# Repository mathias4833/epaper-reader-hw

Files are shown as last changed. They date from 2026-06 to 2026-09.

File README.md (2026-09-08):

# E-Paper Reader

A small battery-powered e-paper reader built around a custom PCB.

<p align="center">
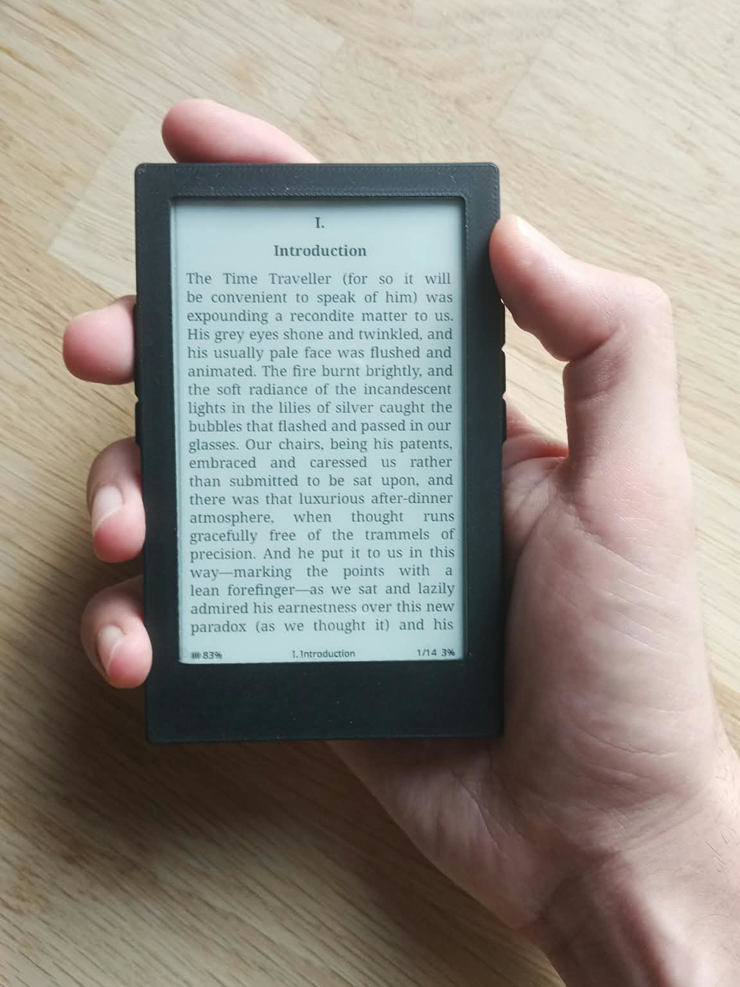
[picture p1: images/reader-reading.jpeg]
The reader displaying The Time Machine, held in one hand
  
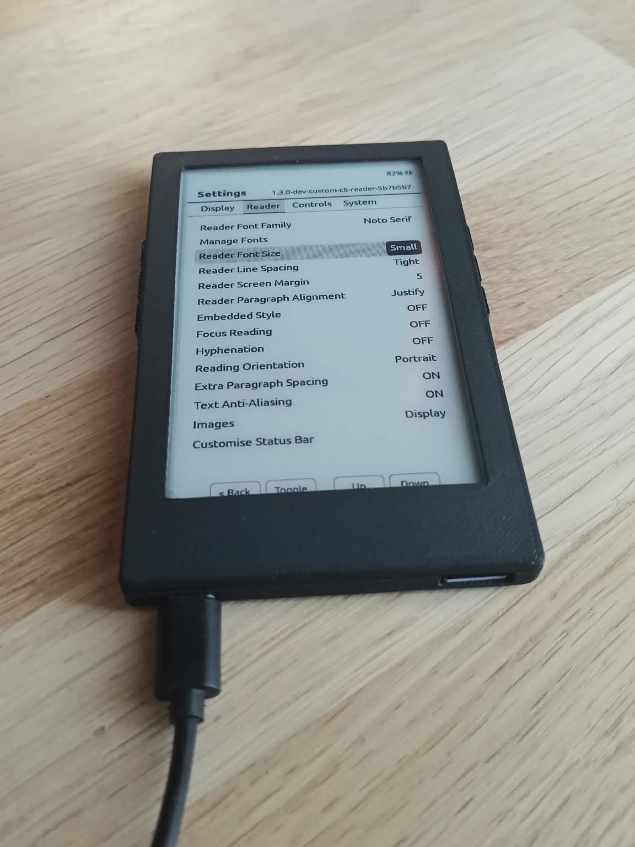
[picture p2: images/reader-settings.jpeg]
The assembled reader showing CrossPoint Reader settings
  
</p>

*Quick demo of the UI and double-tap page turning:*

https://github.com/user-attachments/assets/651f01a9-5495-4bea-b6eb-84c9eb2a8fab

The Xteink X4 was the starting point for this project. I liked the idea of a small reader with physical buttons, but wanted to design the electronics myself.

The board uses an ESP32-C6 and runs [my fork of CrossPoint Reader](https://github.com/mathias4833/crosspoint-reader).

This is very much a V1. It works, but I already have several changes planned for V2.

## PCB

The schematic and PCB were designed in KiCad.

<p align="center">
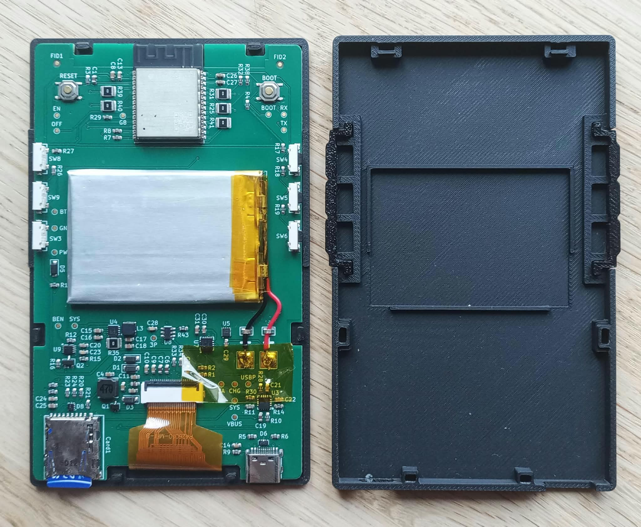
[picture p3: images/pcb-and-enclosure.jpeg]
Assembled PCB with battery, next to the enclosure back cover
  
</p>

| Front | Back |
|---|---|
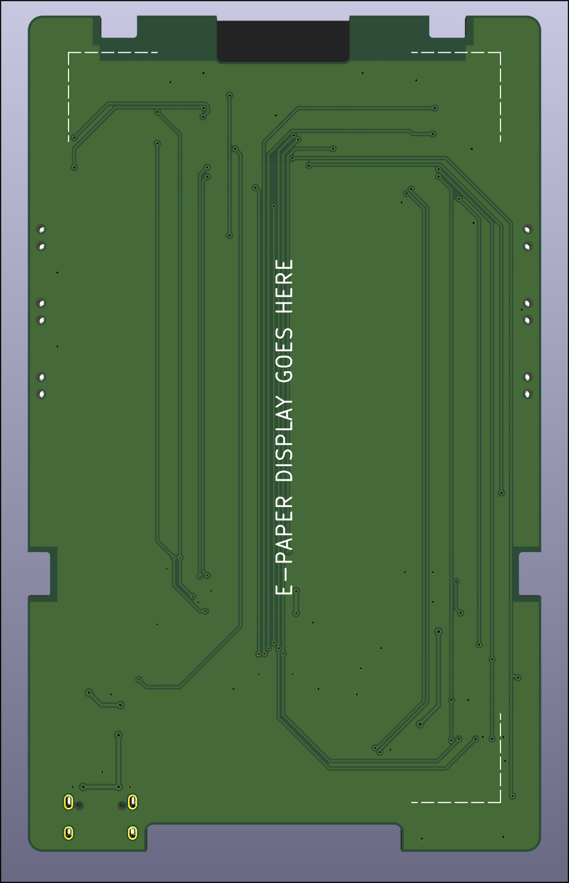
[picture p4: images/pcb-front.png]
PCB render of the display side
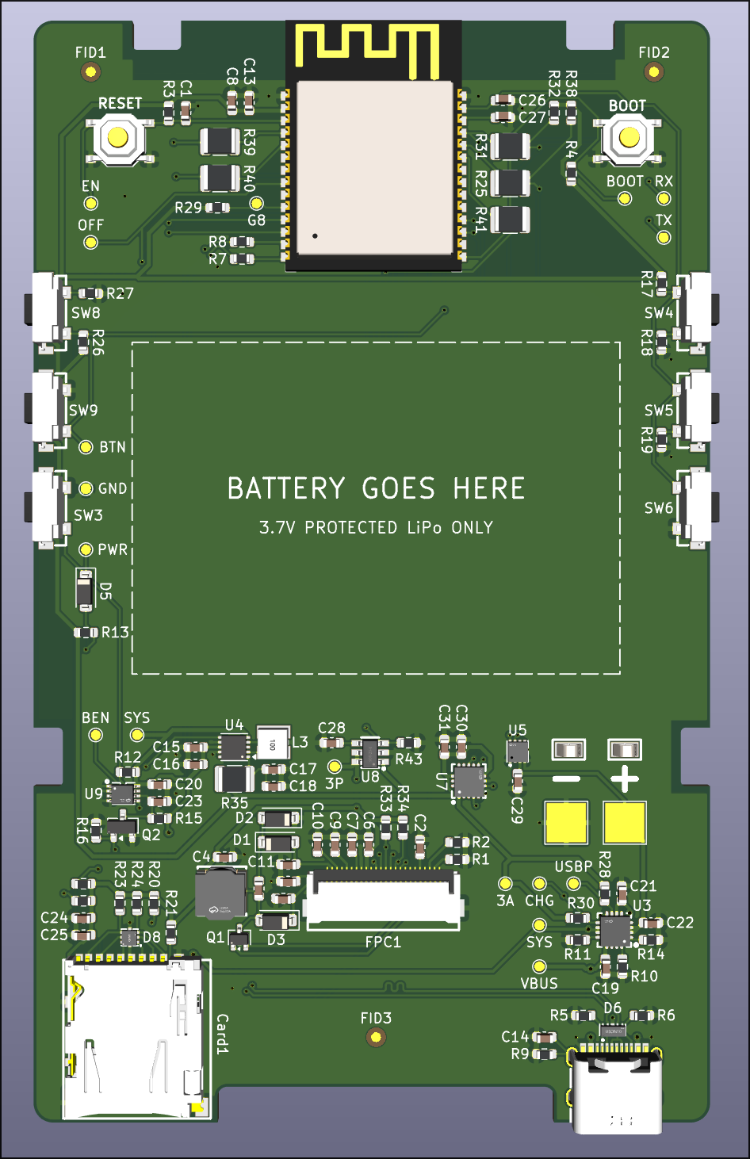
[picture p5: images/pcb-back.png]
PCB render of the component side
|  |  |

## Specifications

  |                     |                                                |
  |---------------------|------------------------------------------------|
  | MCU                 | ESP32-C6-WROOM-1-N8                            |
  | Memory              | 8 MB flash, 512 KB SRAM                        |
  | Display             | 4.26" Good Display GDEQ0426T82, 800 x 480      |
  | Storage             | microSD                                        |
  | Battery             | 600 mAh Li-Po                                  |
  | USB-C               | Of course :)                                   |
  | Charging controller | BQ24074                                        |
  | Voltage regulator   | TPS63031 3.3 V buck-boost                      |
  | Battery gauge       | MAX17048                                       |
  | Controls            | 6 physical side buttons                        |
  | Accelerometer       | LIS3DHTR, 3-axis                               |
  | PCB                 | 2 layers, 1.2 mm                               |
  | Dimensions          | Approx. 116 x 72 x 7.5 mm, including enclosure |

## Hardware

Power comes from a single-cell Li-ion battery. A BQ24074 handles charging and powers the reader from USB when plugged in. A TPS63031 generates the 3.3 V rail, and a MAX17048 keeps track of the battery level.

The display and microSD card share the SPI bus and are both on switchable power rails. The fuel gauge and accelerometer stay powered, since their idle current is low enough that there wasn't much to gain from switching them off (3uA and 0.5uA).

## Schematic

<p align="center">
  <a href="images/schematic.svg">
    Complete KiCad schematic
  </a>
</p>

## Cost

In a batch of five, the parts and fabrication comes to roughly 60€ per reader.

| Part | Approx. cost per reader |
|---|---:|
| PCB components | 20€ |
| PCB fabrication and assembly | ~15€ |
| 4.26" e-paper display | ~17-19€ |
| 600 mAh battery | ~8€ |
| 3D-printed enclosure | ~0.50€ |
| **Total** | **~60€** |

This is a rough estimate. Shipping and imports duties aren't included as they vary a lot depending on where you live, and you'll also need a microSD card and a soldering iron to attach the battery.

## Design decisions

### Layout

I wanted the reader to stay thin, so using through-hole parts was never really an option. I also wanted to avoid paying for assembly on both sides of the PCB (it's super expensive!), which meant keeping all components on the back. 
The buttons are thus on the sides. I used TPU for the button pieces in the enclosure, which makes them much nicer to press than rigid printed buttons.

I originally wanted the final assembly to be completely solderless. I looked for a low-profile battery connector on LCSC but couldn't find anything slim enough. Looking back, there were probably a few decent options I missed, but hey, it's the first version. In the end, I added two large solder pads and called it a day. The battery wires pass through two small metal loops first in order to provide strain relief before reaching the pads.
### ESP32-C6

Obviously my first choice was the ESP32-C3. It is what the Xteink X4 uses, and its power consumption is very good.

The problem was flash. Recent CrossPoint builds are a little over 6 MB, and the Xteink's 16 MB flash is split into two 6.25 MB application partitions so that OTA updates can keep both the old and new firmware around. That wasn't going to work with the C3 modules I could find, which were limited to 4MB flash.

The ESP32-S3 would have solved that, but it also consumes more power than I wanted for an ereader that spends most of its life asleep. 

I eventually found an ESP32-C6 module with 8 MB of flash. That's enough for CrossPoint, but not enough to keep two copies of the firmware around, so OTA updates had to go. USB flashing is good enough for me anyway.

### Power gating

I was using a cheap microSD card and didn't know how much current it would draw while idle. Since standby power matters a lot I didn't want to rely on the SD card behaving well.

So I added a switchable power rail for peripherals that don't need to stay on. When the reader goes to sleep, the firmware can cut their power completely instead of depending on their own low-power modes.

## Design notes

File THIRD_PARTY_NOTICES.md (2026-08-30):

# Third-party assets

Some symbols, footprints and 3D models in this repository were imported from
the EasyEDA, LCSC and JLCPCB component libraries using JLCImport.

These assets are included to keep the KiCad project portable. They are not
covered by the project's CERN-OHL-W-2.0 license and remain subject to their
original terms.

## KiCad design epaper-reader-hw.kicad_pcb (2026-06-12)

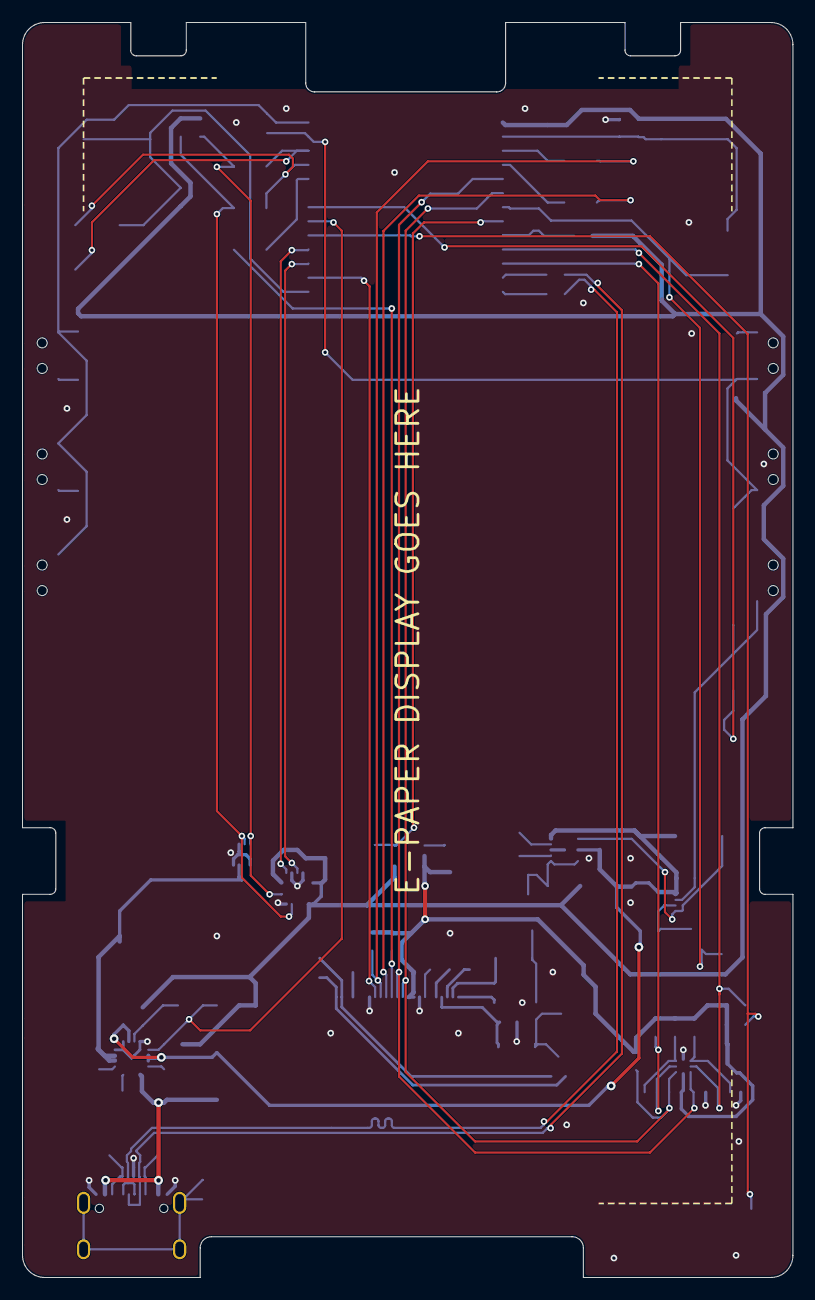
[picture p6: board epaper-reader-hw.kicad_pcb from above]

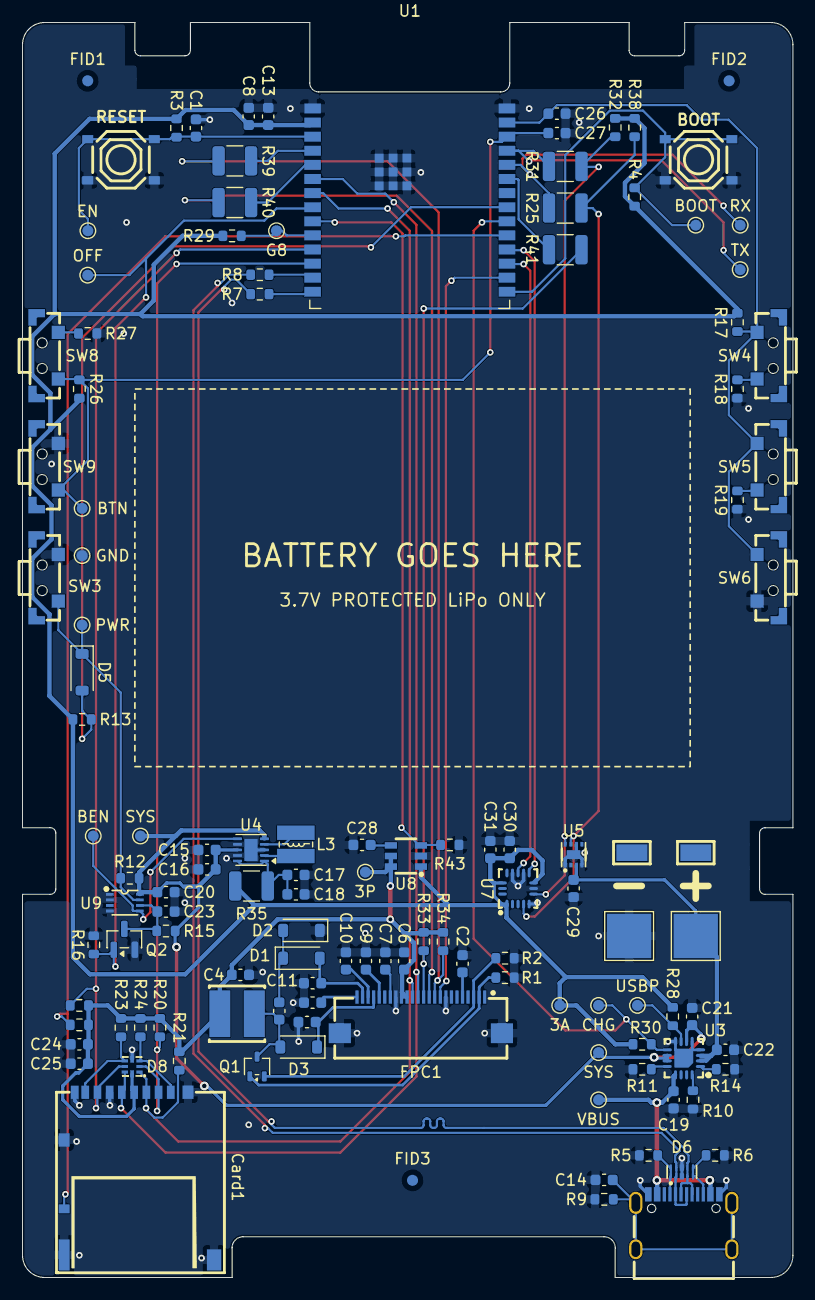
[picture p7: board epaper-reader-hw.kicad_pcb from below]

Board: 2 copper layers, 69.4 x 113.0 mm, 126 parts (125 on the bottom side), 67 nets.

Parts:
BMECH1: Battery_50x34x3mm
C1: 1uF/16V(10%); C_0603_1608Metric
C2, C3, C4, C5, C9, C10, C11: 4.7uF/25V; C_0603_1608Metric
C6, C7: 1uF/50V; C_0603_1608Metric
C8: 10uF/25V(20%); C_0603_1608Metric
C12: 1uF/25V; C_0603_1608Metric
C13: 100nF/50V(10%); C_0603_1608Metric
C14: 4.7nF; C_0603_1608Metric
C15, C17, C18, C25, C31: 10uF; C_0603_1608Metric
C16, C20: 0.1uF; C_0603_1608Metric
C19: 1uF; C_0603_1608Metric
C21, C22: 4.7uF; C_0603_1608Metric
C23, C28: 1nF; C_0603_1608Metric
C24, C29, C30: 100nF; C_0603_1608Metric
C26, C27: 10nF; C_0603_1608Metric
Card1: DM3AT-SF-PEJM5
D1, D2, D3: MBR0530; D_SOD-123
D5: 1N4148W; D_SOD-123
D6: TPD4E05U06QDQARQ1
D8: TPD6E004RSER
DMECH1: EInk_Display_105p33x62p37x0p926mm
FID1, FID2, FID3: Fiducial; Fiducial_1mm_Mask2mm
FPC1: FPC-05FB-24PH20
L1: XRNR5020-47UH_M
L3: 1.5uH; SPM3020-1R5MA
Q1: Si1308EDL; SOT-323_SC-70
Q2: 2N7002; SOT-23
R1, R9, R16: 1M; R_0603_1608Metric
R2: 2R2; R_0603_1608Metric
R3, R14, R17, R18, R20, R21, R22, R23, R24, R26, R27, R29, R32, R33, R34, R38: 10k; R_0603_1608Metric
R4, R19: 3.3k; R_0603_1608Metric
R5, R6: 5.1k(1%); R_0603_1608Metric
R7, R8: 22R; R_0603_1608Metric
R10: 3.6k; R_0603_1608Metric
R11: 3k; R_0603_1608Metric
R12: 200k; R_0603_1608Metric
R13: 47k; R_0603_1608Metric
R15, R28, R30, R42, R43: 100k; R_0603_1608Metric
R25, R31, R35: 0R; R_1210_3225Metric
R39, R40, R41: R0; R_1210_3225Metric
SR1: STRAIN_RELIEF_RING1; RH-5015
SR2: STRAIN_RELIEF_RING2; RH-5015
SW1: SW_RESET; TS-1187A-B-A-B
SW2: SW_BOOT; TS-1187A-B-A-B
SW3: SW_POWER; TSB001A3526B
SW4: SW_LEFT1; TSB001A3526B
SW5: SW_LEFT2; TSB001A3526B
SW6: SW_LEFT3; TSB001A3526B
SW8: SW_RIGHT1; TSB001A3526B
SW9: SW_RIGHT2; TSB001A3526B
TP1, TP2, TP4, TP5, TP6, TP7, TP8, TP9, TP10, TP12, TP13, TP14, TP15, TP16, TP17, TP18, TP20: TestPoint; TestPoint_Pad_D1.0mm
TP3: BAT+; TestPoint_Pad_4.0x4.0mm
TP11: BAT-; TestPoint_Pad_4.0x4.0mm
U1: ESP32-C6-WROOM-1
U3: BQ24074RGTR
U4: TPS63031DSK; WSON-10-1EP_2.5x2.5mm_P0.5mm_EP1.2x2mm
U5: MAX17048G_T10
U7: LIS3DHTR_C15134
U8: TPS22918DBVR
U9: SN74LVC1G74DCUR_C70285
USBC1: TYPE-C-31-M-12

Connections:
+3V3_AON: C8.1, C13.1, C30.1, C31.1, R3.1, R4.1, R13.1, R17.1, R26.1, R28.2, R29.1, R30.2, R32.1, R35.2, R38.1, TP4.1 (1_1), U1.2 (3V3), U7.1 (VDD_IO), U7.8 (CS), U7.14 (VDD), U8.1 (VIN)
+3V3_PERIPH: C4.1, C6.2, C24.1, C25.1, Card1.4 (VDD), D8.8 (VCC), FPC1.15 (VDDIO), FPC1.16 (VCI), L1.1, R20.1, R21.1, R22.1, R23.1, R24.1, R33.1, R34.1, R42.1, TP13.1 (1_1), U8.5 (QOD), U8.6 (VOUT)
/CC1: D6.1 (IO1), D6.10 (NC), R5.1, USBC1.A5 (CC1)
/CC2: D6.5 (IO5), D6.6 (NC), R6.1, USBC1.B5 (CC2)
/DAT1: Card1.8 (DAT1), D8.5 (IO4), R23.2
/DAT2: Card1.1 (DAT2), D8.3 (IO3), R24.2
/DN: D6.2 (IO2), D6.9 (NC), R8.1, USBC1.A7 (D-), USBC1.B7 (D-)
/DP: D6.4 (IO4), D6.7 (NC), R7.1, USBC1.A6 (D+), USBC1.B6 (D+)
/GDR: FPC1.2 (GDR), Q1.1 (G), R1.1
/PREVGH: C5.1, D3.1 (K), FPC1.21 (VGH)
/PREVGL: C11.2, D1.2 (A), FPC1.23 (VGL)
/RESE: FPC1.3 (RESE), Q1.2 (S), R2.1
/VCOM: C12.2, FPC1.24 (VCOM)
ACCEL_INT1: U1.17 (GPIO19), U7.11 (INT1)
ACCEL_INT2: U1.18 (GPIO20), U7.9 (INT2)
BAT_CHG_N: R30.1, TP14.1 (1_1), U1.20 (GPIO22), U3.9 (~CHG)
BTN_LEFT_ADC: C26.1, R17.2, SW4.1, SW5.1, SW6.1, U1.27 (GPIO2/ADC1_CH2)
BTN_POWER_N: D5.2 (A), R13.2, U1.21 (GPIO23)
BTN_RIGHT_ADC: C27.1, R26.2, SW8.1, SW9.1, TP9.1 (1_1), U1.26 (GPIO3/ADC1_CH3)
BUCK_EN: TP12.1 (1_1), U4.6 (EN), U9.5 (Q)
EINK_BUSY: FPC1.9 (BUSY), U1.16 (GPIO18)
EINK_CS: FPC1.12 (CS#), R33.2, R41.2
EINK_DC: FPC1.11 (DC), R40.1
EINK_RST: FPC1.10 (RES#), R34.2, R39.1
ESP32_BOOT: R4.2, SW2.1, SW2.2, TP6.1 (1_1), U1.15 (GPIO9)
ESP32_EN: C1.1, R3.2, SW1.1, SW1.2, TP5.1 (1_1), U1.3 (EN/CHIP_PU)
ESP32_GPIO8: R29.2, TP7.1 (1_1), U1.10 (GPIO8)
GND: C1.2, C2.1, C4.2, C5.2, C6.1, C7.1, C8.2, C9.1, C10.1, C11.1, C12.1, C13.2, C14.1, C15.2, C16.1, C17.2, C18.2, C19.1, C20.1, C21.1, C22.2, C23.2, C24.2, C25.2, C26.2, C27.2, C28.1, C29.2, C30.2, C31.2, Card1.6 (VSS), Card1.9 (DET_B), Card1.10 (SHIELD), Card1.12 (SHIELD), Card1.13 (SHIELD), Card1.14 (SHIELD), D2.1 (K), D6.3 (GND), D6.8 (GND), D8.4 (GND), FPC1.8 (BS1), FPC1.17 (VSS), FPC1.25 (Shield1), FPC1.26 (Shield2), Q2.2 (S), R1.2, R2.2, R5.2, R6.2, R9.1, R10.2, R11.2, R14.2, R16.2, R18.2, R19.2, R27.2, R43.2, SW1.3, SW1.4, SW2.3, SW2.4, SW3.2, SW6.2, SW9.2, TP11.1 (1_1), TP16.1 (1_1), U1.1 (GND), U1.28 (GND), U1.29 (GND), U3.4 (~CE), U3.5 (EN2), U3.8 (VSS), U3.17 (VSS), U4.3 (PGND), U4.7 (PS/SYNC), U4.9 (GND), U4.11 (PGND), U5.1 (CTG), U5.4 (GND), U5.6 (QSTRT), U5.9 (GND), U7.5 (GND), U7.7 (SDO/SA0), U7.10 (RES), U7.12 (GND), U8.2 (GND), U9.1 (CLK), U9.2 (D), U9.4 (GND), USBC1.A1B12 (GND), USBC1.B1A12 (GND)
I2C_SCL: R25.2, R38.2, U5.7 (SCL), U7.4 (SCL/SPC)
I2C_SDA: R31.2, R32.2, U5.8 (SDA), U7.6 (SDA/SDI/SDO)
unnamed: C3.1, D1.1 (K), D2.2 (A)
unnamed: C3.2, D3.2 (A), L1.2, Q1.3 (D)
unnamed: C7.2, FPC1.18 (VDD)
unnamed: C9.2, FPC1.20 (VSH1)
unnamed: C2.2, FPC1.5 (VSH2)
unnamed: C10.2, FPC1.22 (VSL)
unnamed: C23.1, Q2.3 (D), R15.2, U9.6 (CLR#)
unnamed: R18.1, SW4.2
unnamed: R19.1, SW5.2
unnamed: R27.1, SW8.2
unnamed: R41.1, U1.23 (GPIO15)
unnamed: R40.2, U1.5 (MTDI/GPIO5/ADC1_CH5)
unnamed: R39.2, U1.4 (MTMS/GPIO4/ADC1_CH4)
unnamed: R11.1, U3.12 (ILIM)
unnamed: R10.1, U3.16 (ISET)
unnamed: R14.1, U3.1 (TS)
unnamed: C17.1, C18.1, R35.1, U4.1 (VOUT), U4.10 (FB)
unnamed: L3.2, U4.4 (L1)
unnamed: L3.1, U4.2 (L2)
unnamed: C28.2, U8.4 (CT)
unnamed: C14.2, R9.2, USBC1.1 (SHIELD), USBC1.2 (SHIELD), USBC1.3 (SHIELD), USBC1.4 (SHIELD)
PERIPH_EN: R43.1, U1.9 (GPIO1/ADC1_CH1/XTAL_32K_N), U8.3 (ON)
PWR_BTN_N: D5.1 (K), R12.1, SW3.1, TP17.1 (1_1), U9.7 (PRE#)
PWR_OFF: Q2.1 (G), R16.1, TP18.1 (1_1), U1.8 (GPIO0/ADC1_CH0/XTAL_32K_P)
SD_CS: Card1.2 (DAT3/CD), D8.2 (IO2), R20.2, U1.12 (GPIO11)
SD_DET_N: Card1.11 (DET_A), R42.2, U1.19 (GPIO21)
SD_MISO: Card1.7 (DAT0), D8.6 (IO5), R22.2, U1.11 (GPIO10)
SPI_MOSI: Card1.3 (CMD), D8.1 (IO1), FPC1.14 (SDI), R21.2, U1.7 (MTDO/GPIO7)
SPI_SCLK: Card1.5 (CLK), D8.7 (IO6), FPC1.13 (SCLK), U1.6 (MTCK/GPIO6/ADC1_CH6)
SYS_PWR: C15.1, C16.2, C20.2, C21.2, R12.2, R15.1, TP10.1 (1_1), TP20.1 (1_1), U3.6 (EN1), U3.10 (OUT), U3.11 (OUT), U4.5 (VIN), U4.8 (VINA), U9.8 (VCC)
UART_RX_DBG: R25.1, TP2.1 (1_1), U1.24 (U0RXD/GPIO17)
UART_TX_DBG: R31.1, TP1.1 (1_1), U1.25 (U0TXD/GPIO16)
USB_DN: R8.2, U1.13 (GPIO12/USB_D-)
USB_DP: R7.2, U1.14 (GPIO13/USB_D+)
USB_PRESENT_N: R28.1, TP15.1 (1_1), U3.7 (~PGOOD)
USB_VBUS: C19.2, TP8.1 (1_1), U3.13 (IN), USBC1.A4B9 (VBUS), USBC1.B4A9 (VBUS)
VBAT: C22.1, C29.1, TP3.1 (1_1), U3.2 (BAT), U3.3 (BAT), U5.3 (VDD)

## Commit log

2026-05-23 Add ESP32-C6 MCU symbol and signal labels
    [epaper-reader-hw.kicad_sch]
2026-05-23 Add ESP32-C6 reset and boot circuitry
    [epaper-reader-hw.kicad_sch]
2026-05-24 Add user buttons schematic
    [epaper-reader-hw.kicad_sch]
2026-05-24 WiP power path
    [epaper-reader-hw.kicad_sch]
2026-05-25 Add power path
    [epaper-reader-hw.kicad_sch]
2026-05-25 WiP soft power latch
    [epaper-reader-hw.kicad_sch]
2026-05-25 Add XC6194AA10ER-G symbol / footprint / model + fix espressif warning
    [epaper-reader-hw.kicad_sch]
2026-05-26 Add new symbols + add microsd + ESD protection
    [epaper-reader-hw.kicad_sch]
2026-05-26 Fix PWR_OFF connected to UART0
    [epaper-reader-hw.kicad_sch]
2026-05-26 Use adc ladder buttons and fix gpio8
    [epaper-reader-hw.kicad_sch]
2026-05-26 Add charging state
    [epaper-reader-hw.kicad_sch]
2026-05-26 use same spi to reduce number pins
    [epaper-reader-hw.kicad_sch]
2026-05-26 Add footprints
    [epaper-reader-hw.kicad_sch]
2026-05-29 Finish schematics and start pcb
    [epaper-reader-hw.kicad_pcb, epaper-reader-hw.kicad_sch]
2026-05-29 Use custom footprint + 3d models
    [epaper-reader-hw.kicad_pcb, epaper-reader-hw.kicad_sch]
2026-05-30 Place components and add battery+screen props
    [epaper-reader-hw.kicad_pcb, epaper-reader-hw.kicad_sch]
2026-05-30 Change side buttons reference
    [epaper-reader-hw.kicad_pcb, epaper-reader-hw.kicad_sch]
2026-05-30 add charge pump on the pcb
    [epaper-reader-hw.kicad_pcb]
2026-05-31 Add accelerometer
    [epaper-reader-hw.kicad_sch]
2026-05-31 Add 2nd power rail for deep sleep
    [epaper-reader-hw.kicad_sch]
2026-05-31 Add datasheets and component
    [epaper-reader-hw.kicad_sch]
2026-06-01 Make first attempt at layouting
    [epaper-reader-hw.kicad_pcb, epaper-reader-hw.kicad_sch]
2026-06-02 Move charge pump and battery connector
    [epaper-reader-hw.kicad_pcb]
2026-06-02 Clean up pcb labels and positions
    [epaper-reader-hw.kicad_pcb]
2026-06-02 Improve positions of reset/boot buttons
    [epaper-reader-hw.kicad_pcb]
2026-06-02 Bigger 0R resistors and tighter layout for bigger battery
    [epaper-reader-hw.kicad_pcb, epaper-reader-hw.kicad_sch]
2026-06-04 clean up schematics
    [epaper-reader-hw.kicad_pcb, epaper-reader-hw.kicad_sch]
2026-06-04 Add holes for securing the shell
    [epaper-reader-hw.kicad_pcb]
2026-06-04 Add eink cable notch
    [epaper-reader-hw.kicad_pcb]
2026-06-04 Fix tests pads positions and add battery+eink borders
    [epaper-reader-hw.kicad_pcb, epaper-reader-hw.kicad_sch]
2026-06-04 Replace FPC connector to have top contact
    [epaper-reader-hw.kicad_pcb, epaper-reader-hw.kicad_sch]
2026-06-05 Add missing .step 3d model for export
    [epaper-reader-hw.kicad_pcb]
2026-06-05 Add rounded corners and tune board settings
    [epaper-reader-hw.kicad_pcb]
2026-06-05 Add netlist patterns
    [epaper-reader-hw.kicad_pcb]
2026-06-06 Start routing
    [epaper-reader-hw.kicad_pcb]
2026-06-06 Add more routes (but it's starting to get messy)
    [epaper-reader-hw.kicad_pcb]
2026-06-06 Spaghetti routes
    [epaper-reader-hw.kicad_pcb, epaper-reader-hw.kicad_sch]
2026-06-07 Less spaghetti
    [epaper-reader-hw.kicad_pcb]
2026-06-07 Cleanly route the charge pump + majors signals
    [epaper-reader-hw.kicad_pcb, epaper-reader-hw.kicad_sch]
2026-06-07 Finish routing components
    [epaper-reader-hw.kicad_pcb, epaper-reader-hw.kicad_sch]
2026-06-07 Clean up silkscreen
    [epaper-reader-hw.kicad_pcb, epaper-reader-hw.kicad_sch]
2026-06-07 Add lcsc infos
    [epaper-reader-hw.kicad_pcb, epaper-reader-hw.kicad_sch]
2026-06-07 Fix copper on antenna and rename lcsc fields
    [epaper-reader-hw.kicad_pcb, epaper-reader-hw.kicad_sch]
2026-06-09 Add fiducial / clean up
    [epaper-reader-hw.kicad_pcb, epaper-reader-hw.kicad_sch]
2026-06-12 Update PCB grounding and fiducial placement settings
    [epaper-reader-hw.kicad_pcb, epaper-reader-hw.kicad_sch]
2026-07-08 Clean up obsolete todo
    [epaper-reader-hw.kicad_sch]
2026-07-08 Ignore generated KiCad production files and reports
2026-09-29 Fix display silkscreen outline (fixes #3)
